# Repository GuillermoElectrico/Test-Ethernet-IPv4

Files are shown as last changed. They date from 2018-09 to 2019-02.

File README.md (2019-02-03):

# Test-Ethernet-IPv4

El Arduino Test Ethernet IPv4  (a partir de ahora Test Ethernet) es un proyecto que surgió de la necesidad de poder probar el cableado y funcionamiento de una red Ethernet. Su función principal es la de verificar la conexión mediante un cliente DHCP y posteriores pruebas de ping a la información obtenida. Posteriormente se añadió pruebas de DNS y calidad de la salida a Internet. 

Con estas sencillas pruebas se puede confirmar que por lo menos el cable a probar sincroniza y da enlace, además de probar la correcta configuración del puerto del switch (si se usan VLAN), así como los servicios esenciales de la propia red (DHCP, DNS). 

Esto es algo básico y esencial a probar en una red, pero siempre ha sido necesario disponer de un ordenador, un portátil o un equipo de pruebas de red comercial (muy caros, por cierto). Con el Test Ethernet evitamos necesitar esos equipos y los problemas que suelen dar al realizar las pruebas, como la lentitud de adquisición del DHCP o los problemas que suelen dar las pilas TCP/IP en los sistemas operativos ante conexiones y desconexiones constantes de la interfaz Ethernet. El Arduino Test Ethernet realiza estas pruebas en apenas unos segundos y sin la mediación de ningún sistema operativo.

### Materiales necesarios

A continuación, pongo los materiales necesarios para el montaje de un Test Ethernet. 
Alguna de las piezas puede tener varias configuraciones posibles, se indicarán con un asterisco.

Los dispositivos necesarios son:
#### Pantalla 2.8” TFT LCD HX8347 Shield (puede valer otra como las de 2.4”, pero habría que editar el sketch y probar si es compatible con la librería usada).

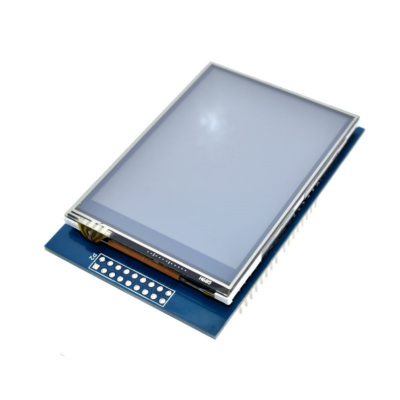
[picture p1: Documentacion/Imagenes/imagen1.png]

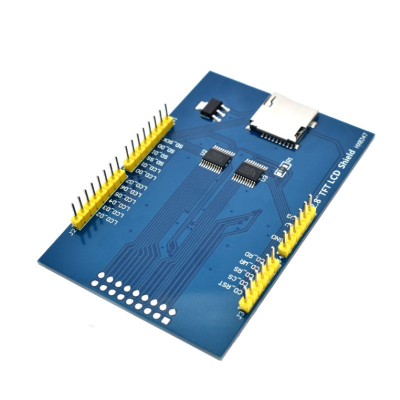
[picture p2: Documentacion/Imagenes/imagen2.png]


#### Arduino Uno + Shield Ethernet W5100 *
 
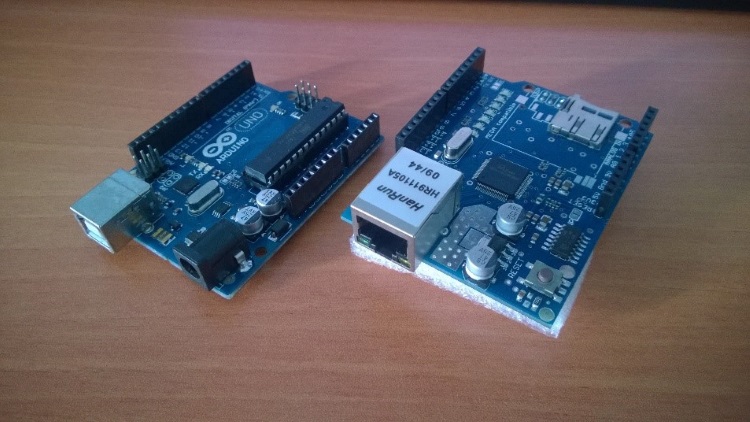
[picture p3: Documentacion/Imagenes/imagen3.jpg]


*Arduino Uno + Shield Ethernet W5100 puede ser sustituido por un Arduino Ethernet*:
 
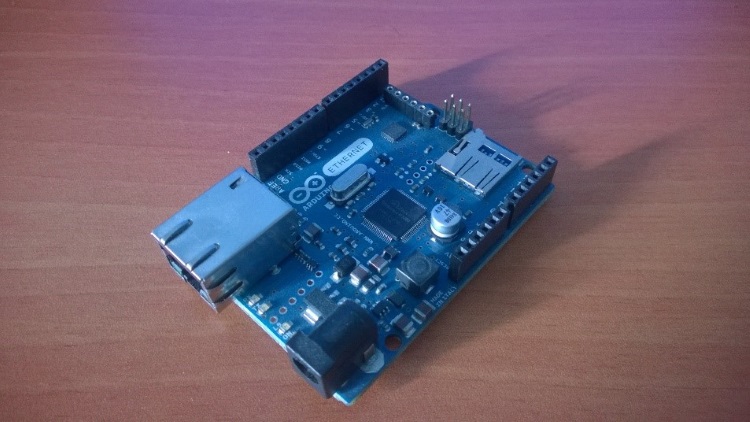
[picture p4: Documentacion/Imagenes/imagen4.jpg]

 
Es la unión de dos en uno, ocupando menos espacio, aunque con el inconveniente de ser más caro que los otros dos juntos (dependiendo donde se adquieran) y la necesidad de tener que adquirir un cable FTDI 5V a mayores para poder subir el programa. 

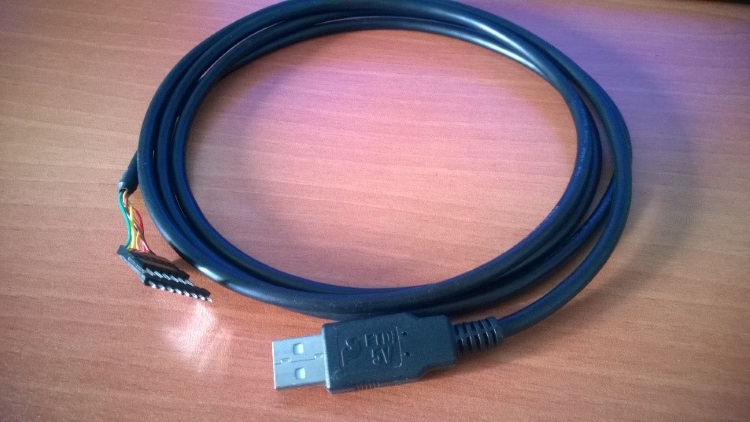
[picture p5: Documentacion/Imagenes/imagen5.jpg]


#### Shield Alimentación LiPo + Batería LiPo *
 
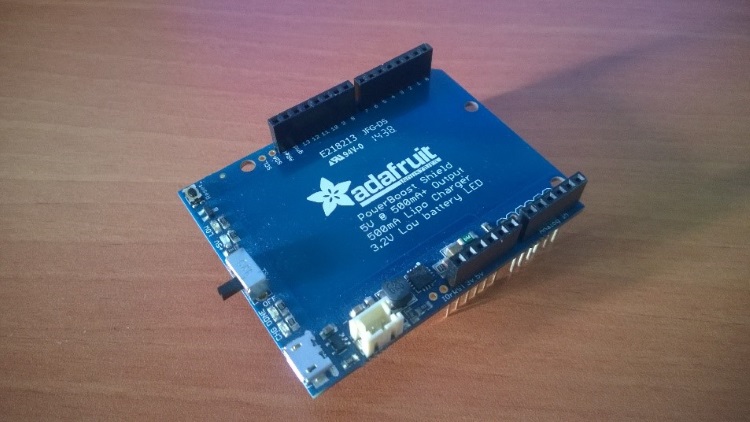
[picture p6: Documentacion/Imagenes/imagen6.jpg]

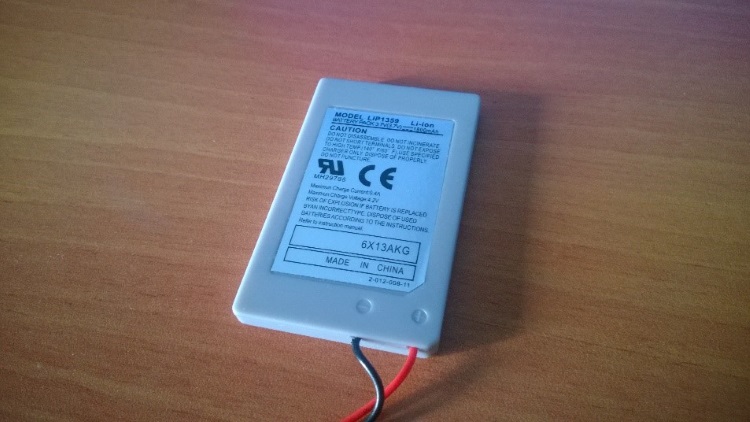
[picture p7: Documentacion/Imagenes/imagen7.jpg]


Si queremos que el equipo sea portátil, necesitaremos alimentarlo de alguna manera. Una opción son las Shield de alimentación, la ventaja es la fácil implantación en el conjunto, así como la posibilidad de ser recargables. La principal desventaja es el precio de la propia Shield.

*Puede ser sustituido por una pila o conjunto de pilas de 9V y un interruptor. Quedaría bien si se pudiese añadir o acoplar a una caja para poder imprimirla en 3D (esto está aún en desarrollo)

#### Pines Hembra Arduino (Opcional)

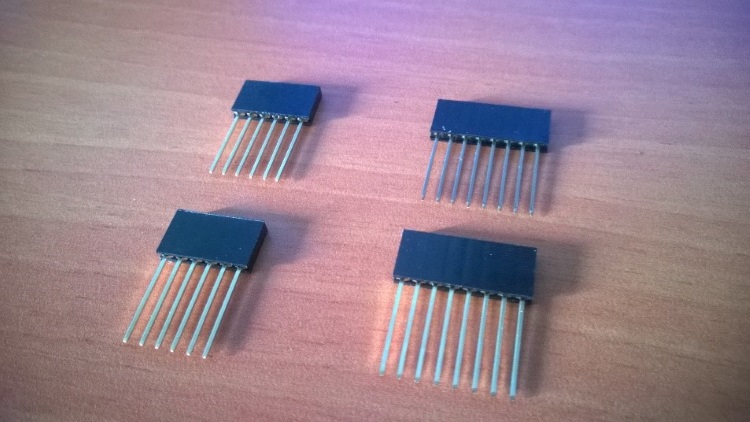
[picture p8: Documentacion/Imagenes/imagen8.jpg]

 
Para evitar que quede mal ajustada la pantalla con el conector Ethernet se pueden usar unos pines Arduino como extensores a fin de evitar el contacto entre las placas y evitar posibles cortocircuitos.

Además de estos materiales será necesario disponer de un ordenador con un puerto USB así como del IDE Arduino Configurado (recomendable, aunque se puede usar otro, añadiendo las librerías necesarias).

### Montaje

En esto no hay mucha ciencia, es tan sencillo como ir uniendo Shield al Arduino Uno (o Arduino Ethernet) finalizando el sándwich con la Pantalla 2.8”. Siempre evitando que las Shield se lleguen a tocar o que queden forzadas (en ese caso usar los Pines Hembra Arduino, viendo si es necesario en el caso, acortar los pines para que quede más compacto)
Al final tendrá que quedar más o menos como esto:

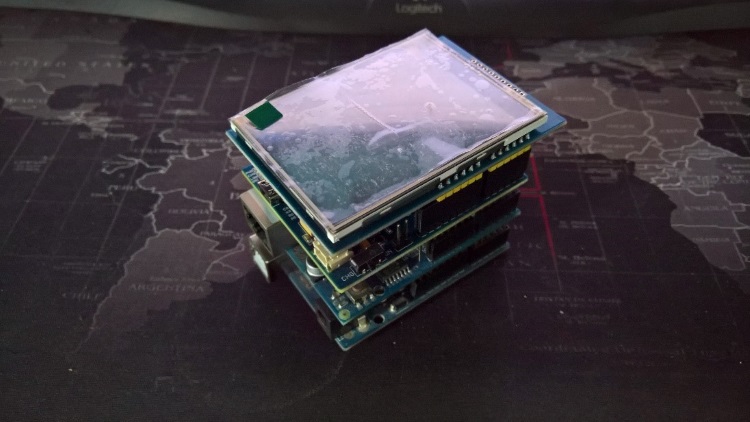
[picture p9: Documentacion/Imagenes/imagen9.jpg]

 
O si se usa un Arduino Ethernet:
 
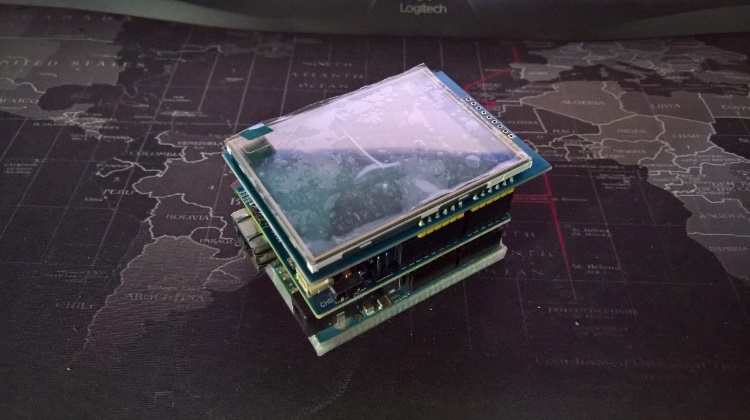
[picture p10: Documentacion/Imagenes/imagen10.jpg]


### Subir programa 

Una vez montado ya solo queda configurar y subir el programa al Arduino. Para ello se recomienda usar la versión del IDE Arduino Configurado, ya que dispone de las librerías modificadas para el correcto funcionamiento del programa. 

Está disponible en: https://1drv.ms/u/s!At1AwrxoRqguw-Y5gXUSvRbdpju0hA

* No es más que un arduino-1.8.6 configurado en modo portable (simplemente añadido un directorio con el nombre portable en raiz del directorio) y simplificadas las librerías a las mínimas necesarias.

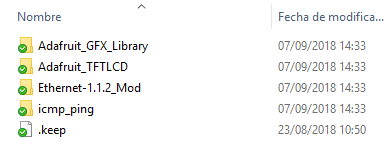
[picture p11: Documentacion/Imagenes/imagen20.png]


Para poder extraer alguna información de las librerías oficiales de Arduino ha sido necesario modificarlas para tal fin. Pero, por el hecho de modificarlas, ya no es compatible con otros programas que usen esas librerías y genera errores. Con lo cual solo quedan dos opciones, o sustituir temporalmente las librerías originales por las librerías modificadas para subir el programa (luego volviendo a restablecer las originales) o usar el “arduino-1.8.6_Test_Ethernet_IPv4”, que ya incluye las librerías y está comprobado su correcto funcionamiento.
En esta guía se centrará en el uso de “arduino-1.8.6_Test_Ethernet_IPv4”, por ser la manera más fácil de actuar.
Para subir el programa solo hay que conectar el Arduino Uno (o Arduino Ethernet con el cable FTDI) al equipo e iniciar el ejecutable “arduino.exe”.
Tras eso nos parecerá la ventana siguiente:

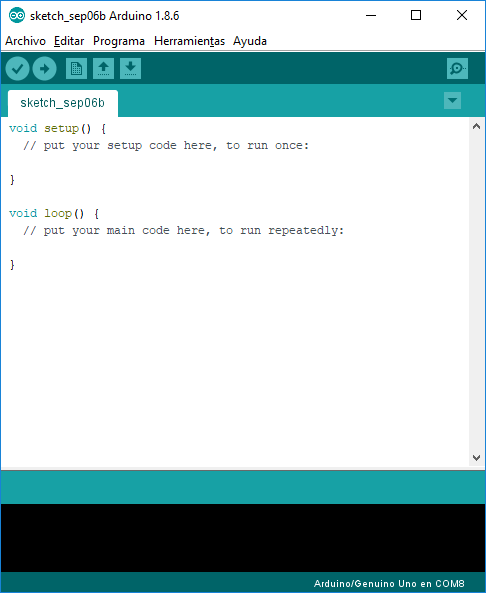
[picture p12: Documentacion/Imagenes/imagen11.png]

 
Lo primero de todo hay que confirmar el tipo de placa que se está usando, así como el puerto COM donde está conectado el Arduino. Para ello hay que ir a “Herramientas -> Placa” y “Herramientas -> Port” y marcar la opción que dispongamos. Suele aparecer un único puerto COMX, ese es el que hay que usar, en caso de que aparezcan varios, el de mayor número suele ser, si no probar con cada uno.

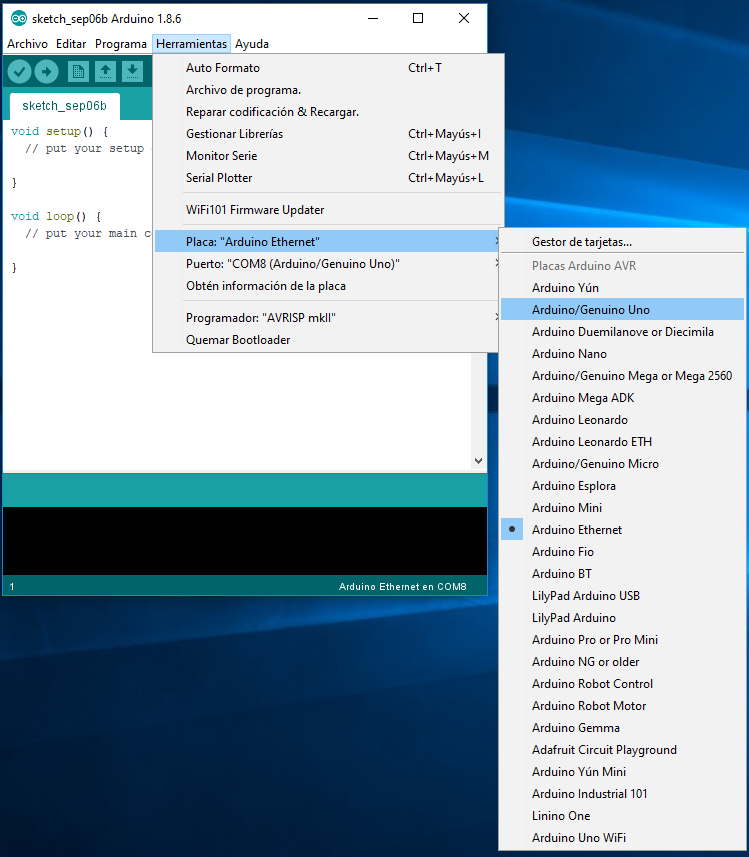
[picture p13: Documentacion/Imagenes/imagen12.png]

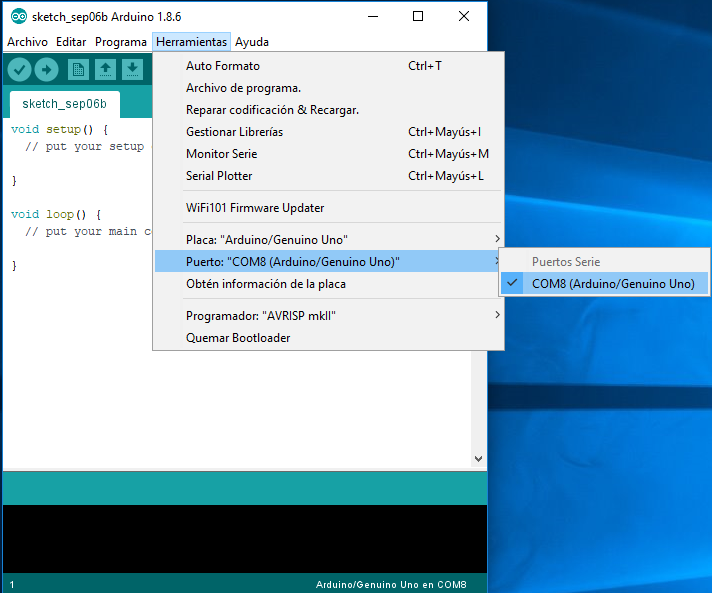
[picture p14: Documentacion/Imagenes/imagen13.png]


Una vez selecciona el dispositivo Arduino correcto y el puerto, procedemos a abrir el programa a cargar. Para ello ir a “Archivo -> Abrir” y buscar el archivo “Test_Ethernet_V5.ino” dentro de la carpeta “Test_Ethernet_V5”.

Lo único que hay que cambiar, si es necesario, sería la dirección de hostname  que se usa para probar el servidor DNS y a la cual se realizarán los pings de prueba de acceso a internet. Por defecto es www.google.com y no es necesario cambiarlo para que funcione. 

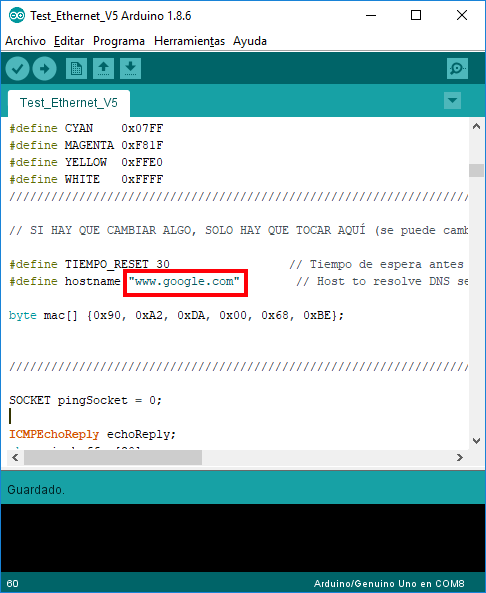
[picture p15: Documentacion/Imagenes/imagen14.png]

 
Como se puede ver, también se puede personalizar la dirección mac (opcional), por si se quiere hacer pruebas static lease o tener varios equipos funcionando en una red simultáneamente.
Ahora solo lo que queda por que hacer es pinchar en el icono superior con una flecha a la derecha para comenzar a subir el programa al Arduino.

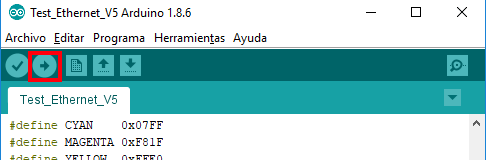
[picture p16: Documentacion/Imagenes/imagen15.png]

  
Una vez finalizado el proceso, si no hay errores o problemas, debería de aparecer el siguiente mensaje, además de mostrar texto en la pantalla.

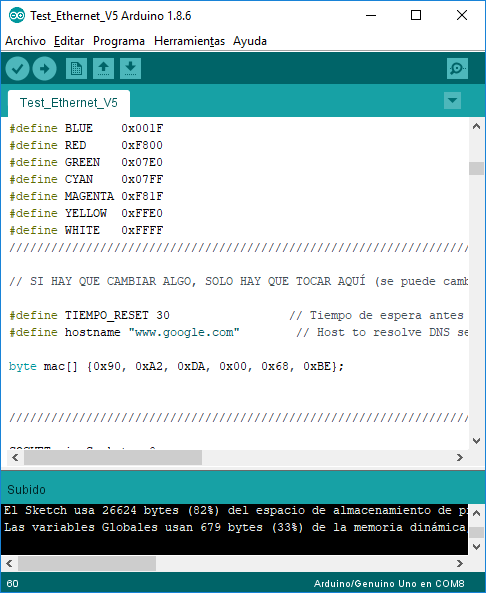
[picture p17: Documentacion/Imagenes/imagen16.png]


Ahora en la pantalla debería de ponerse negra con texto en blanco.

### Cómo funciona 

Una vez montado subido el programa y encendido debería de aparecer en la pantalla lo siguiente:
 
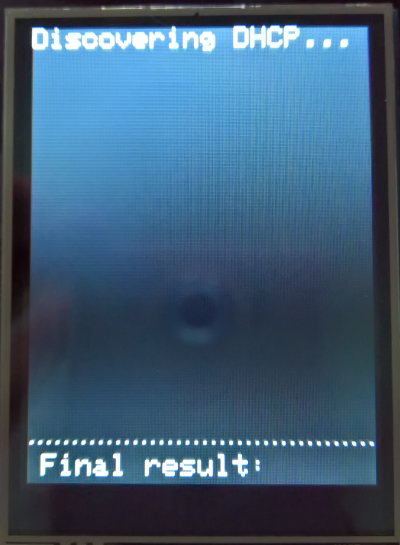
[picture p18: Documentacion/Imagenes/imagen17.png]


En este momento el Arduino está ya funcionando y realizando el test. Es esta situación el Test Arduino está funcionando el cliente DHCP y está esperando respuesta del servidor DHCP. 

Si el cable no está conectado, defectuoso, o el switch está mal configurado o no están funcionando el servicio DHCP, aparecerá la siguiente pantalla. 

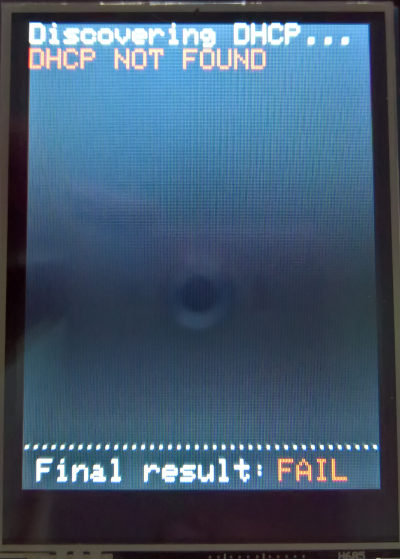
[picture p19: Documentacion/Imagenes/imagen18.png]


Es esta se indica que no se ha encontrado servidor DHCP operativo o correcto. Para verificar si el problema es el cable o el servicio DHCP, se puede observar si los pilotos led del conector RJ45 están encendidos. En caso de no estar encendidos (tanto el verde como el amarillo) el problema probablemente esté localizado en el cable o en la boca del Switch. Si en caso contrario están encendidos y no obtiene IP, las causa más probable será o una errónea configuración del switch o del servidor. Tras 30 Segundos se reiniciará la prueba.

Si la prueba es satisfactoria aparecería la siguiente pantalla:

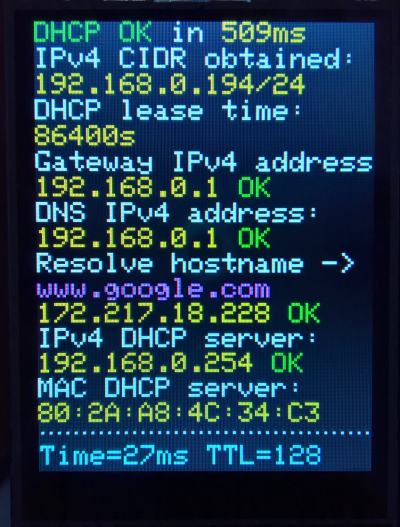
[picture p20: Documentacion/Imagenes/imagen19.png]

 
* Los textos en Blanco son elementos de prueba.
* Los elementos en Amarillo son la información obtenida del test.
* Los elementos en Verde son los resultados satisfactorios del test.*
* Los elementos en Rojo son los resultados fallidos del test.*
* Los elementos en Azul son información adicional al test satisfactorio verde. 

*Principalmente los test Verde o Rojo son resultados de un test de Ping ICMP al elemento Amarillo.

Para reiniciar el test, solo habría que pulsar el boton reset de la placa Arduino.

FIN 😉.

## Actualización 02/02/2019

### Montaje con PCB Minimal especial (Opcional, *alternativa a Arduino Ethernet ya descatalogado)

Para el montaje de esta configuración es necesario un Arduino Uno (o un Atmega328 DIP) + Shield Ethernet W5100, la Shield Alimentación LiPo + Batería LiPo y una placa PCB especial (disponible el gerber y el fzz en la carpeta PCB_Minimalista). 



Puedes mandar fabricar la PCB en JLCPCB o PCBWay (o similar) por entre 2-5$ (10 unidades).

También necesitarías un cristal de cuarzo de 16MHz, dos condensadores de 22pF cerámicos y una resistencia de 10K.

El montaje es sencillo y se resume en las siguientes imágenes (en este montaje es recomendable programar el chip Atmega328 antes de ponerlo en la PCB, seá mediante programador o directamente usando el Arduino UNO y luego sacando el chip).

Simplemente se montan los componentes en la PCB y se sueldan (recomendable montar un zócalo para el Atmega328, por si hay que actualizar el código en un futuro). 



A su vez se suelda en la Shield Alimentación LiPo por debajo, dejando un espacio entre las placas para evitar contactos no deseados.







Ahora lo que hay que hacer es en la Shield Ethernet W5100 es recortar los pines de conexión (ya que se conectará por los hembras superiores) y quitar el conector del ICSP. 





Hay que soldar tres hilos entre los pines 11, 12 y 13 a los pines del ISCP de la Shield Ethernet W5100 para que funcione el bus SPI (en las placas muy antiguas no haría falta, pero en las modernas compatibles con mega es obligatorio).



Una vez soldado, se puede proteger los hilos con cinta o con unas gotas de pegamento para que no se suelten ni se enganchen.

Ya solo falta conectar la batería a la Shield de Alimentación, montar la pantalla y listo. Si habias programado antes de montar el Atmega328 (sea extraido de la placa Arduino UNO o simplemente el chip DIP) una vez que lo enciendas ya estaría funcionando y mostrando información en la pantalla (anteriormente explicado como funciona).

Es una alternativa funcional (y económica) al Arduino Ethernet que ya no se fabrica. Hace mucho más compacto y manejable el montaje final.



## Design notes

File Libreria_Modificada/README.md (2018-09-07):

# Atención

Las librerías aquí expuestas son modificaciones de las librerías Ethernet oficiales de Arduino. Lo que quiere decir, que no pueden convivir las dos a la vez en ningún IDE, ya que tecnicamente son lo mismo y dá errores.

Para usar la librería, mover o eliminar el directorio Ethernet de la carpeta libraries del IDE antes de copiar la librería modificada. Una vez subido el sketch, se puede restaurar el directorio original, previa eliminación de la librería modificada.

Actualmente hay dos versiones de la librería Ethernet, la 1.1.2 que solo funciona con las shields W5100 y la nueva 2.0.0 que añade compatibilidad a las shields W5200 y W5500

Actualmente solo funciona el sketch con la versión 1.1.2, ya que en la nueva versión 2.0.0 aún no se es posible realizar Ping ICMP. La librería ya está modificada y probada, pero sin esa función, gran parte de las pruebas no se repueden realizar. Esperando en un futuro poder hacer ICMP y actualizar la librería.

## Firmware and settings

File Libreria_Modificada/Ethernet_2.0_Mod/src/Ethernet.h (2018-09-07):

/* Copyright 2018 Paul Stoffregen
 *
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
 * THE SOFTWARE IS PROVIDED "AS IS", WITHOUT WARRANTY OF ANY KIND, EXPRESS OR IMPLIED,
 * INCLUDING BUT NOT LIMITED TO THE WARRANTIES OF MERCHANTABILITY, FITNESS FOR A
 * PARTICULAR PURPOSE AND NONINFRINGEMENT. IN NO EVENT SHALL THE AUTHORS OR COPYRIGHT
 * HOLDERS BE LIABLE FOR ANY CLAIM, DAMAGES OR OTHER LIABILITY, WHETHER IN AN ACTION
 * OF CONTRACT, TORT OR OTHERWISE, ARISING FROM, OUT OF OR IN CONNECTION WITH THE
 * SOFTWARE OR THE USE OR OTHER DEALINGS IN THE SOFTWARE.
 */

#ifndef ethernet_h_
#define ethernet_h_

// All symbols exposed to Arduino sketches are contained in this header file
//
// Older versions had much of this stuff in EthernetClient.h, EthernetServer.h,
// and socket.h.  Including headers in different order could cause trouble, so
// these "friend" classes are now defined in the same header file.  socket.h
// was removed to avoid possible conflict with the C library header files.


// Configure the maximum number of sockets to support.  W5100 chips can have
// up to 4 sockets.  W5200 & W5500 can have up to 8 sockets.  Several bytes
// of RAM are used for each socket.  Reducing the maximum can save RAM, but
// you are limited to fewer simultaneous connections.
#if defined(RAMEND) && defined(RAMSTART) && ((RAMEND - RAMSTART) <= 2048)
#define MAX_SOCK_NUM 4
#else
#define MAX_SOCK_NUM 8
#endif

// By default, each socket uses 2K buffers inside the Wiznet chip.  If
// MAX_SOCK_NUM is set to fewer than the chip's maximum, uncommenting
// this will use larger buffers within the Wiznet chip.  Large buffers
// can really help with UDP protocols like Artnet.  In theory larger
// buffers should allow faster TCP over high-latency links, but this
// does not always seem to work in practice (maybe Wiznet bugs?)
//#define ETHERNET_LARGE_BUFFERS


#include <Arduino.h>
#include "Client.h"
#include "Server.h"
#include "Udp.h"

enum EthernetLinkStatus {
	Unknown,
	LinkON,
	LinkOFF
};

enum EthernetHardwareStatus {
	EthernetNoHardware,
	EthernetW5100,
	EthernetW5200,
	EthernetW5500
};

class EthernetUDP;
class EthernetClient;
class EthernetServer;
class DhcpClass;

class EthernetClass {
private:
	static IPAddress _dnsServerAddress;
	
	//**************************************
	static IPAddress _dhcpServerAddress; //*
    static unsigned long _dhcpLeaseTime; //*
	//**************************************
	
	static DhcpClass* _dhcp;
public:
	// Initialise the Ethernet shield to use the provided MAC address and
	// gain the rest of the configuration through DHCP.
	// Returns 0 if the DHCP configuration failed, and 1 if it succeeded
	static int begin(uint8_t *mac, unsigned long timeout = 60000, unsigned long responseTimeout = 4000);
	static int maintain();
	static EthernetLinkStatus linkStatus();
	static EthernetHardwareStatus hardwareStatus();

	// Manaul configuration
	static void begin(uint8_t *mac, IPAddress ip);
	static void begin(uint8_t *mac, IPAddress ip, IPAddress dns);
	static void begin(uint8_t *mac, IPAddress ip, IPAddress dns, IPAddress gateway);
	static void begin(uint8_t *mac, IPAddress ip, IPAddress dns, IPAddress gateway, IPAddress subnet);
	static void init(uint8_t sspin = 10);

	static void MACAddress(uint8_t *mac_address);
	static IPAddress localIP();
	static IPAddress subnetMask();
	static IPAddress gatewayIP();
	static IPAddress dnsServerIP() { return _dnsServerAddress; }
	
	//********************************************************************
	static IPAddress dhcpServerIP() { return _dhcpServerAddress; }      //*
    static unsigned long dhcpLeaseTime() { return _dhcpLeaseTime; } //*
	//********************************************************************

	void setMACAddress(const uint8_t *mac_address);
	void setLocalIP(const IPAddress local_ip);
	void setSubnetMask(const IPAddress subnet);
	void setGatewayIP(const IPAddress gateway);
	void setDnsServerIP(const IPAddress dns_server) { _dnsServerAddress = dns_server; }
	void setRetransmissionTimeout(uint16_t milliseconds);
	void setRetransmissionCount(uint8_t num);

	friend class EthernetClient;
	friend class EthernetServer;
	friend class EthernetUDP;
private:
	// Opens a socket(TCP or UDP or IP_RAW mode)
	static uint8_t socketBegin(uint8_t protocol, uint16_t port);
	static uint8_t socketBeginMulticast(uint8_t protocol, IPAddress ip,uint16_t port);
	static uint8_t socketStatus(uint8_t s);
	// Close socket
	static void socketClose(uint8_t s);
	// Establish TCP connection (Active connection)
	static void socketConnect(uint8_t s, uint8_t * addr, uint16_t port);
	// disconnect the connection
	static void socketDisconnect(uint8_t s);
	// Establish TCP connection (Passive connection)
	static uint8_t socketListen(uint8_t s);
	// Send data (TCP)
	static uint16_t socketSend(uint8_t s, const uint8_t * buf, uint16_t len);
	static uint16_t socketSendAvailable(uint8_t s);
	// Receive data (TCP)
	static int socketRecv(uint8_t s, uint8_t * buf, int16_t len);
	static uint16_t socketRecvAvailable(uint8_t s);
	static uint8_t socketPeek(uint8_t s);
	// sets up a UDP datagram, the data for which will be provided by one
	// or more calls to bufferData and then finally sent with sendUDP.
	// return true if the datagram was successfully set up, or false if there was an error
	static bool socketStartUDP(uint8_t s, uint8_t* addr, uint16_t port);
	// copy up to len bytes of data from buf into a UDP datagram to be
	// sent later by sendUDP.  Allows datagrams to be built up from a series of bufferData calls.
	// return Number of bytes successfully buffered
	static uint16_t socketBufferData(uint8_t s, uint16_t offset, const uint8_t* buf, uint16_t len);
	// Send a UDP datagram built up from a sequence of startUDP followed by one or more
	// calls to bufferData.
	// return true if the datagram was successfully sent, or false if there was an error
	static bool socketSendUDP(uint8_t s);
	// Initialize the "random" source port number
	static void socketPortRand(uint16_t n);
};

extern EthernetClass Ethernet;


#define UDP_TX_PACKET_MAX_SIZE 24

class EthernetUDP : public UDP {
private:
	uint16_t _port; // local port to listen on
	IPAddress _remoteIP; // remote IP address for the incoming packet whilst it's being processed
	uint16_t _remotePort; // remote port for the incoming packet whilst it's being processed
	uint16_t _offset; // offset into the packet being sent

protected:
	uint8_t sockindex;
	uint16_t _remaining; // remaining bytes of incoming packet yet to be processed
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

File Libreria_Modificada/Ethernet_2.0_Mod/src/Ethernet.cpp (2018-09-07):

/* Copyright 2018 Paul Stoffregen
 *
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
 * THE SOFTWARE IS PROVIDED "AS IS", WITHOUT WARRANTY OF ANY KIND, EXPRESS OR IMPLIED,
 * INCLUDING BUT NOT LIMITED TO THE WARRANTIES OF MERCHANTABILITY, FITNESS FOR A
 * PARTICULAR PURPOSE AND NONINFRINGEMENT. IN NO EVENT SHALL THE AUTHORS OR COPYRIGHT
 * HOLDERS BE LIABLE FOR ANY CLAIM, DAMAGES OR OTHER LIABILITY, WHETHER IN AN ACTION
 * OF CONTRACT, TORT OR OTHERWISE, ARISING FROM, OUT OF OR IN CONNECTION WITH THE
 * SOFTWARE OR THE USE OR OTHER DEALINGS IN THE SOFTWARE.
 */

#include <Arduino.h>
#include "Ethernet.h"
#include "utility/w5100.h"
#include "Dhcp.h"

IPAddress EthernetClass::_dnsServerAddress;
//**************************************************
IPAddress EthernetClass::_dhcpServerAddress;
unsigned long EthernetClass::_dhcpLeaseTime;
//**************************************************
DhcpClass* EthernetClass::_dhcp = NULL;

int EthernetClass::begin(uint8_t *mac, unsigned long timeout, unsigned long responseTimeout)
{
	static DhcpClass s_dhcp;
	_dhcp = &s_dhcp;

	// Initialise the basic info
	if (W5100.init() == 0) return 0;
	SPI.beginTransaction(SPI_ETHERNET_SETTINGS);
	W5100.setMACAddress(mac);
	W5100.setIPAddress(IPAddress(0,0,0,0).raw_address());
	SPI.endTransaction();

	// Now try to get our config info from a DHCP server
	int ret = _dhcp->beginWithDHCP(mac, timeout, responseTimeout);
	if (ret == 1) {
		// We've successfully found a DHCP server and got our configuration
		// info, so set things accordingly
		SPI.beginTransaction(SPI_ETHERNET_SETTINGS);
		W5100.setIPAddress(_dhcp->getLocalIp().raw_address());
		W5100.setGatewayIp(_dhcp->getGatewayIp().raw_address());
		W5100.setSubnetMask(_dhcp->getSubnetMask().raw_address());
		SPI.endTransaction();
		_dnsServerAddress = _dhcp->getDnsServerIp();
		//*****************************************************
		_dhcpServerAddress = _dhcp->getDhcpServerIp();
		_dhcpLeaseTime = _dhcp->getdhcpLeaseTime();
		//*****************************************************
		socketPortRand(micros());
	}
	return ret;
}

void EthernetClass::begin(uint8_t *mac, IPAddress ip)
{
	// Assume the DNS server will be the machine on the same network as the local IP
	// but with last octet being '1'
	IPAddress dns = ip;
	dns[3] = 1;
	begin(mac, ip, dns);
}

void EthernetClass::begin(uint8_t *mac, IPAddress ip, IPAddress dns)
{
	// Assume the gateway will be the machine on the same network as the local IP
	// but with last octet being '1'
	IPAddress gateway = ip;
	gateway[3] = 1;
	begin(mac, ip, dns, gateway);
}

void EthernetClass::begin(uint8_t *mac, IPAddress ip, IPAddress dns, IPAddress gateway)
{
	IPAddress subnet(255, 255, 255, 0);
	begin(mac, ip, dns, gateway, subnet);
}

void EthernetClass::begin(uint8_t *mac, IPAddress ip, IPAddress dns, IPAddress gateway, IPAddress subnet)
{
	if (W5100.init() == 0) return;
	SPI.beginTransaction(SPI_ETHERNET_SETTINGS);
	W5100.setMACAddress(mac);
#if ARDUINO > 106 || TEENSYDUINO > 121
	W5100.setIPAddress(ip._address.bytes);
	W5100.setGatewayIp(gateway._address.bytes);
	W5100.setSubnetMask(subnet._address.bytes);
#else
	W5100.setIPAddress(ip._address);
	W5100.setGatewayIp(gateway._address);
	W5100.setSubnetMask(subnet._address);
#endif
	SPI.endTransaction();
	_dnsServerAddress = dns;
}

void EthernetClass::init(uint8_t sspin)
{
	W5100.setSS(sspin);
}

EthernetLinkStatus EthernetClass::linkStatus()
{
	switch (W5100.getLinkStatus()) {
		case UNKNOWN:  return Unknown;
		case LINK_ON:  return LinkON;
		case LINK_OFF: return LinkOFF;
		default:       return Unknown;
	}
}

EthernetHardwareStatus EthernetClass::hardwareStatus()
{
	switch (W5100.getChip()) {
		case 51: return EthernetW5100;
		case 52: return EthernetW5200;
		case 55: return EthernetW5500;
		default: return EthernetNoHardware;
	}
}

int EthernetClass::maintain()
{
	int rc = DHCP_CHECK_NONE;
	if (_dhcp != NULL) {
		// we have a pointer to dhcp, use it
		rc = _dhcp->checkLease();
		switch (rc) {
		case DHCP_CHECK_NONE:
			//nothing done
			break;
		case DHCP_CHECK_RENEW_OK:
		case DHCP_CHECK_REBIND_OK:
			//we might have got a new IP.
			SPI.beginTransaction(SPI_ETHERNET_SETTINGS);
			W5100.setIPAddress(_dhcp->getLocalIp().raw_address());
			W5100.setGatewayIp(_dhcp->getGatewayIp().raw_address());
			W5100.setSubnetMask(_dhcp->getSubnetMask().raw_address());
			SPI.endTransaction();
			_dnsServerAddress = _dhcp->getDnsServerIp();
			//***************************************************
			_dhcpServerAddress = _dhcp->getDhcpServerIp();
			_dhcpLeaseTime = _dhcp->getdhcpLeaseTime();
			//***************************************************
			break;
		default:
			//this is actually an error, it will retry though
			break;
		}
	}
	return rc;
}


void EthernetClass::MACAddress(uint8_t *mac_address)
{
	SPI.beginTransaction(SPI_ETHERNET_SETTINGS);
	W5100.getMACAddress(mac_address);
	SPI.endTransaction();
}

IPAddress EthernetClass::localIP()
{
	IPAddress ret;
	SPI.beginTransaction(SPI_ETHERNET_SETTINGS);
	W5100.getIPAddress(ret.raw_address());
	SPI.endTransaction();
	return ret;
}

IPAddress EthernetClass::subnetMask()
{
	IPAddress ret;
	SPI.beginTransaction(SPI_ETHERNET_SETTINGS);
	W5100.getSubnetMask(ret.raw_address());
	SPI.endTransaction();
	return ret;
}

IPAddress EthernetClass::gatewayIP()
{
	IPAddress ret;
	SPI.beginTransaction(SPI_ETHERNET_SETTINGS);
	W5100.getGatewayIp(ret.raw_address());
	SPI.endTransaction();
	return ret;
}

void EthernetClass::setMACAddress(const uint8_t *mac_address)
{
	SPI.beginTransaction(SPI_ETHERNET_SETTINGS);
	W5100.setMACAddress(mac_address);
	SPI.endTransaction();
}

void EthernetClass::setLocalIP(const IPAddress local_ip)
{
	SPI.beginTransaction(SPI_ETHERNET_SETTINGS);
	IPAddress ip = local_ip;
	W5100.setIPAddress(ip.raw_address());
	SPI.endTransaction();
}

void EthernetClass::setSubnetMask(const IPAddress subnet)
{
	SPI.beginTransaction(SPI_ETHERNET_SETTINGS);
	IPAddress ip = subnet;
	W5100.setSubnetMask(ip.raw_address());
	SPI.endTransaction();
}

void EthernetClass::setGatewayIP(const IPAddress gateway)
{
	SPI.beginTransaction(SPI_ETHERNET_SETTINGS);
	IPAddress ip = gateway;
	W5100.setGatewayIp(ip.raw_address());
	SPI.endTransaction();
}

void EthernetClass::setRetransmissionTimeout(uint16_t milliseconds)
{
	if (milliseconds > 6553) milliseconds = 6553;
	SPI.beginTransaction(SPI_ETHERNET_SETTINGS);
	W5100.setRetransmissionTime(milliseconds * 10);
	SPI.endTransaction();
}

void EthernetClass::setRetransmissionCount(uint8_t num)
{
	SPI.beginTransaction(SPI_ETHERNET_SETTINGS);
	W5100.setRetransmissionCount(num);
	SPI.endTransaction();
}






EthernetClass Ethernet;

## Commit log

2018-09-20 Add Lipo Link
2018-11-23 Update files and add PCB minimalist.
    [ArduinoMinimal_TestIPv4.fzz]
